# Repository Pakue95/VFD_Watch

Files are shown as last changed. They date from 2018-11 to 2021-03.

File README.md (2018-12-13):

# VFD Watch Project

This project was originally inspired by Johngineer's [ChronodeVFD](https://blog.adafruit.com/2014/10/29/chronodevfd-a-watch-by-johngineer-wearablewednesday/) project. However no concrete design information were available therefore this project was born.

The goal was to create a mobile driver circuit for the common IVL2-5/7 vacuum fluorescent display, that is powered by a single cell battery. The datasheet of the display can be found on the [Loststreak](http://loststeak.com/ivl2-75-vfd-datasheets/) blog.

## Circuit elements

### Microcontroller
An **ESP32 WROOM-32** module is used as a microcontroller for the display and wireless communication. It is interfaced fo r programming via a **FT231XS** USB-Serial converter.

### Battery voltage regulation
The choice for the battery driver IC fell on the **MP3120** single cell 1.2A step up module as it can handle very low battery voltages and still start up. If wireless communication is used during the power up of the display the step-up module won't be able to supply enough power from a normal Alkaline cell to the ESP32 and a brownout reset will occur. Primary lithium cells, 2 Alkaline batteries or LiIon should be sufficient to power all functions at the same time.

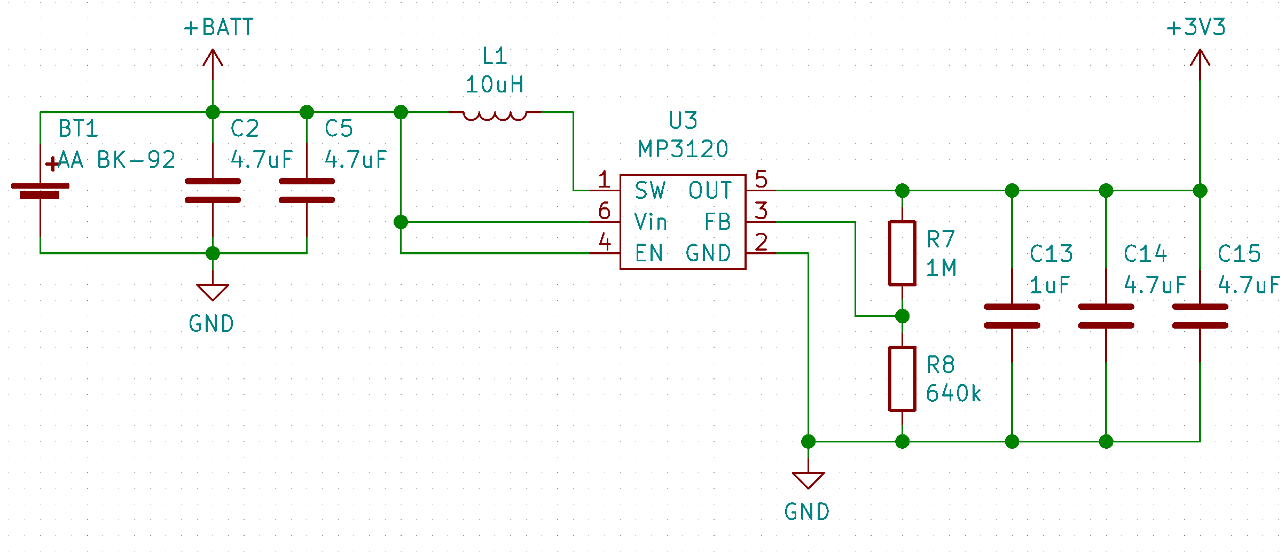
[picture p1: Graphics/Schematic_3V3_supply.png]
Schematic of the 3.3V supply


### VFD driver
The display is driven by a 24V rail from a **MCP1663** step-up converter and high-side switches (**TBD62783A**) to power the segments. The filament is driven from the 3.3V rail and pulse-modulated from a motor H-bridge driver (**DRV8837C**) to achieve an equivalent to the 2.4V @ 60mA power conditions described in the datasheet. The H-bridge design allows an equal brightness of the characters without the use of a complex center-tapped AC circuit.

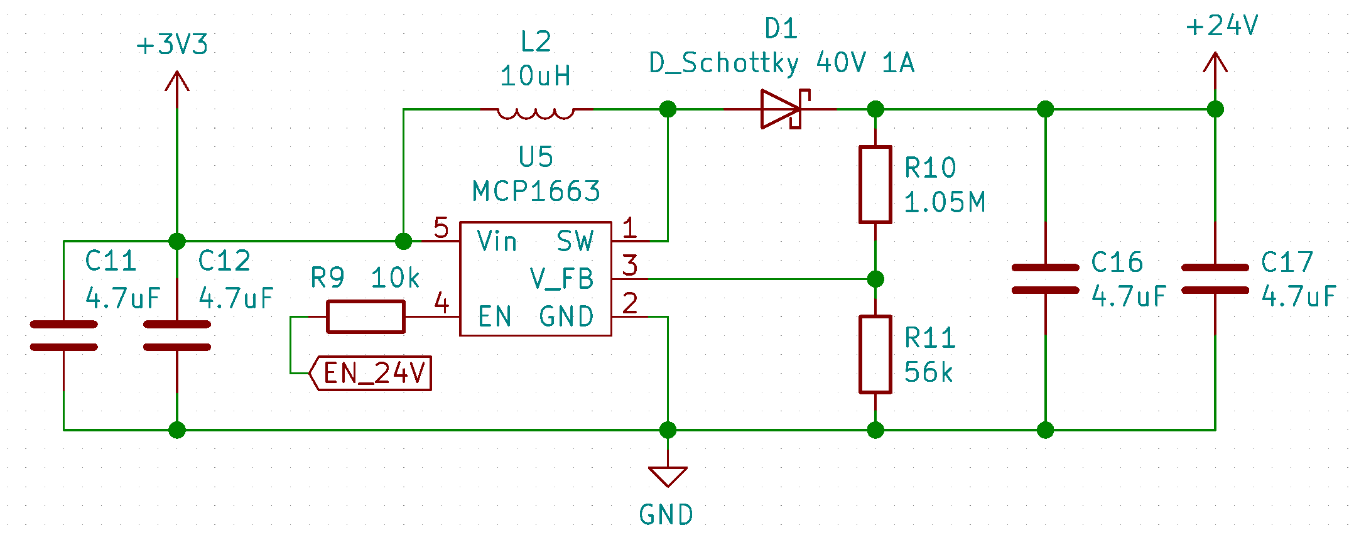
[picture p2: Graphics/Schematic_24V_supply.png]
Schematic of the 24V supply


## Software

### Functions

```cpp
void begin(uint8_t dutyCycle, uint32_t freqMultiplex, uint32_t freqHeat)
```

* ```dutyCycle``` sets the PWM duty cycle of the heating filament. 0-255; typical 120.
* ```freqMultiplex``` sets the rate at which the characters are cycled though (1kHz -> 200Hz total refresh of the display). The timing is controlled in the background by an interrupt function that calls for an update of the currently displayed character. This process runs on core 0 of the ESP32, therefore during WiFi use the display can flicker a bit.
* ```freqHeat``` sets the frequency of the heating filament PWM. The value should be in the kHz range.

```cpp
void deactivate()
```
Turns of the heating filament and the 24V rail to preserve power.

```cpp
void activate()
```
Turns the display back on after a ```deactivate()```.

```cpp
void setHours(uint8_t hours)
```
Sets the first two digits. Range 0-99.

```cpp
void setMinutes(uint8_t minutes)
```
Sets the last two digits. Range 0-99.

```cpp
void setCharacter(char character, int pos)
```
Displays a char (```a-z; 0-9; '-'```) at position ```pos``` (```0-3```)

```cpp
void print(char* text)
```
Similar to ```setCharacter()``` but it displays the first 4 chars of the array.

```cpp
void setSegment(uint8_t segments, uint8_t pos);
```
Sets specific segments of a digit through the use of a byte mask (least to most significant bit). E.g. ```0b00101000``` would set segments ```d``` & ```f```. ```pos``` declares the digit to be changed (```0-3```).

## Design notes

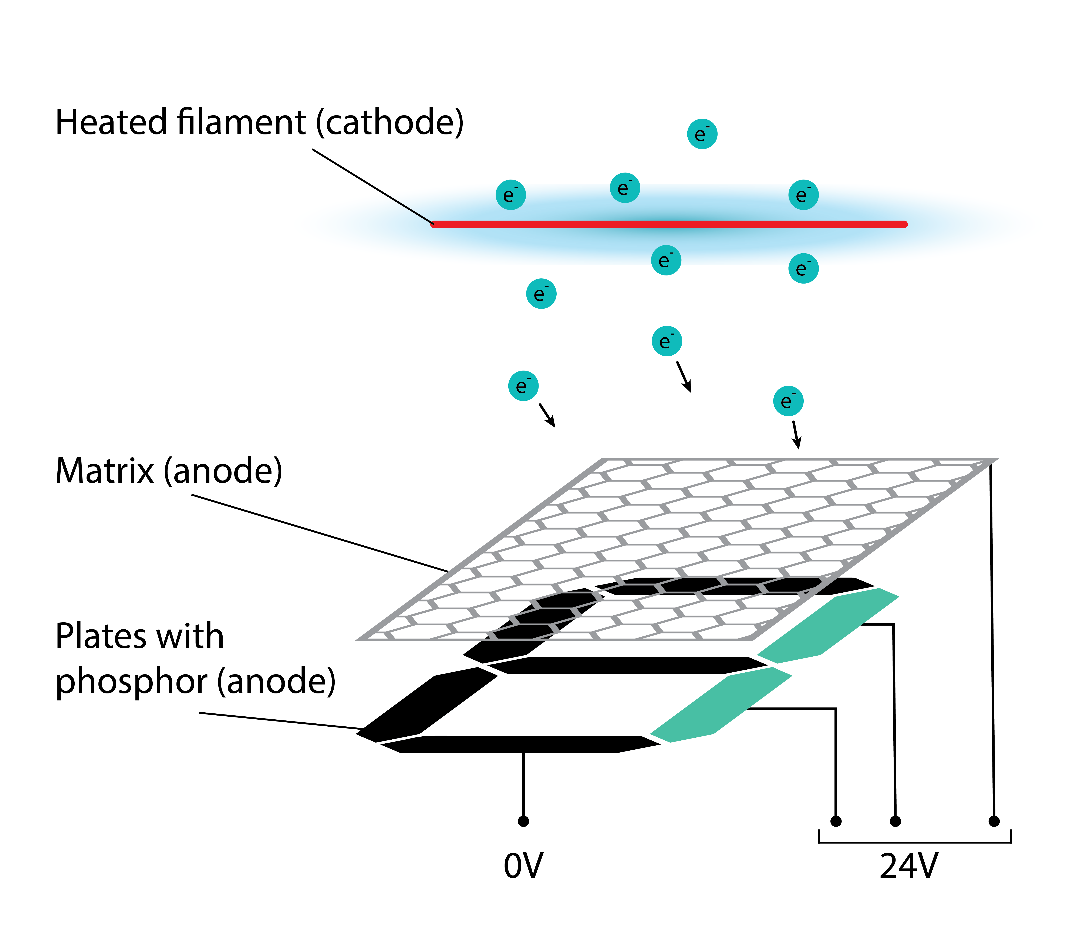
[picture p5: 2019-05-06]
Graphics/VFD_Function/VFD_Function-01.png

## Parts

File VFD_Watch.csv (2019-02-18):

Id | Designator | Package | Quantity | Designation | Supplier and ref
1 | R19,R18,R5,R6,R9,R12,R13,R14,R15,R16,R17 | R_0805_2012Metric | 11 | 10k
2 | C19 | C_1206_3216Metric | 1 | 10uF
3 | U10 | ILV2-5_7 | 1 | IVL2-7_5
4 | REF**,REF**,REF**,REF** | Strap_Holes | 4 | Strap_Holes
5 | U6 | ESP32-WROOM | 1 | ESP32-WROOM
6 | U8,U9 | SOP-18_7.0x12.5mm_P1.27mm | 2 | TBD62783A
7 | U4 | SSOP-20_3.9x8.7mm_P0.635mm | 1 | FT231XS
8 | J2 | PinHeader_1x04_P1.27mm_Vertical | 1 | I2C_Con
9 | U7 | SSOP-28_5.3x10.2mm_P0.65mm | 1 | MCP23017_SS
10 | REF**,REF**,REF**,REF** | Wire_Holes | 4 | Wire_Holes
11 | U1 | SOT-23-5 | 1 | MIC5219-3.3YM5
12 | L2,L1 | L_Taiyo-Yuden_MD-5050 | 2 | 10uH
13 | BT1 | BK-92 | 1 | AA BK-92
14 | C1,C2,C5,C6,C8,C11,C12,C14,C15,C16,C17 | C_0805_2012Metric | 11 | 4.7uF
15 | C3,C4 | C_0805_2012Metric | 2 | 47pF
16 | C9,C10,C18 | C_0805_2012Metric | 3 | 100nF
17 | C13 | C_0805_2012Metric | 1 | 1uF
18 | D1 | D_SOD-323 | 1 | D_Schottky 40V 1A
19 | J1 | USB_Micro-B_Molex_47346-0001 | 1 | USB_B_Micro
20 | Q1 | SOT-363_SC-70-6 | 1 | MBT3904DW1
21 | R1,R2 | R_1206_3216Metric | 2 | 0R
22 | R3,R4 | R_0805_2012Metric | 2 | 27
23 | R7 | R_0805_2012Metric | 1 | 1M
24 | R8 | R_0805_2012Metric | 1 | 640k
25 | R10 | R_0805_2012Metric | 1 | 1.05M
26 | R11 | R_0805_2012Metric | 1 | 56k
27 | SW1 | SW_SPST_EVQP7A | 1 | B1
28 | SW2 | SW_SPST_EVQP7A | 1 | B2
29 | SW3 | SW_SPST_EVQP7A | 1 | B_RES
30 | SW4 | SW_SPST_EVQP7A | 1 | B_0
31 | U2 | WSON-8-1EP_2x2mm_P0.5mm_EP0.9x1.6mm | 1 | DRV8837C
32 | U3 | TSOT-23-6 | 1 | MP3120
33 | U5 | TSOT-23-5 | 1 | MCP1663
34 | C7 | C_0805_2012Metric | 1 | 470pF

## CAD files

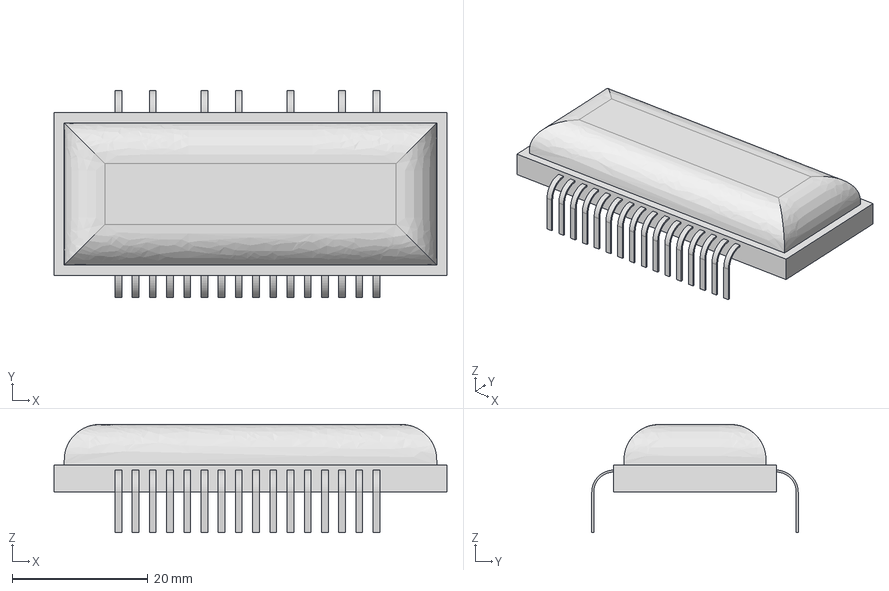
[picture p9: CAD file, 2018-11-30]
3D/VFD_Display v1.step
58.0 x 30.5 x 16.0 mm

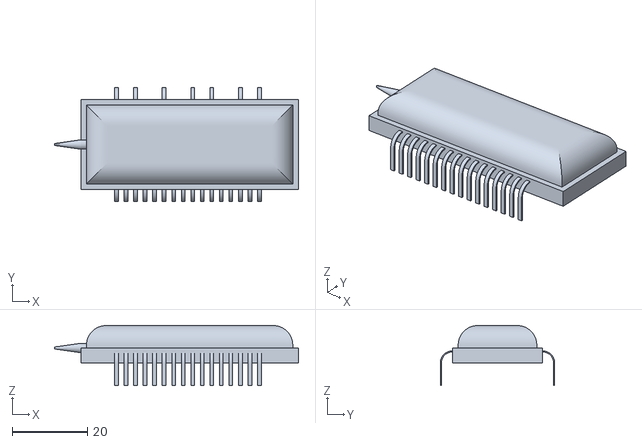
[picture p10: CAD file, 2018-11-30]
3D/VFD_Display v2.stl
65.0 x 30.5 x 16.0

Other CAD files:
3D/VFD_Display v1.iges

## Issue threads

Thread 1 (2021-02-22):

Setting time with buttons

Oliver614, 2021-02-22:
Hi!

I love the project but I'm not very familiar with c++.
Looking through the code there is no obvious way to set the time without WIFI.
Could you please describe a way I could use the buttons to set the time rather than needing to be attached to WIFI?

Regards,
Ollie

Pakue95, 2021-02-26:
Hey Ollie,

Thank!

I use the ESP32 [internal system time](https://docs.espressif.com/projects/esp-idf/en/latest/esp32/api-reference/system/system_time.html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), which is set via NTP, to track the time. You can set is manually if you want with settimeofday() or use a library like this [one](https://www.arduinolibraries.info/libraries/esp32-time).
[Here](https://github.com/Pakue95/VFD_Watch/blob/a7a951d7522ca1ebe2ff7beca40939c133f14d9f/Code/src/main.cpp#L64) is where the time is set and written to the display if you want to have a go at it.

I might be able to implement something over the weekend to set the time with the buttons.

Oliver614, 2021-02-26:
Thankyou that would be interesting to see! i dont know C++ yet so i wouldn't even know to start. but i basically started to write the software again in python as a learning exercise.
I saw there were some python files in the code folder but it was just an empty file. any reason for this? or was it ssomething you were going to work on?

Pakue95, 2021-03-14:
I added a bit of code to set the time with the buttons once the wifi connection fails for a few seconds. Left/Right -> up/down; middle -> set the minutes/finish.

I created the python folder for playing around with [MicroPython](https://micropython.org), but never pushed the code due to some bug with mapping I2C to the pins I had chosen.

Oliver614, 2021-03-14:
Okay nice, I'll have a look. I actually got it working with micropython today but the i2c does seem a little slow to update I'm not sure why but it might be the library I'm using.

Closed 2021-03-14.

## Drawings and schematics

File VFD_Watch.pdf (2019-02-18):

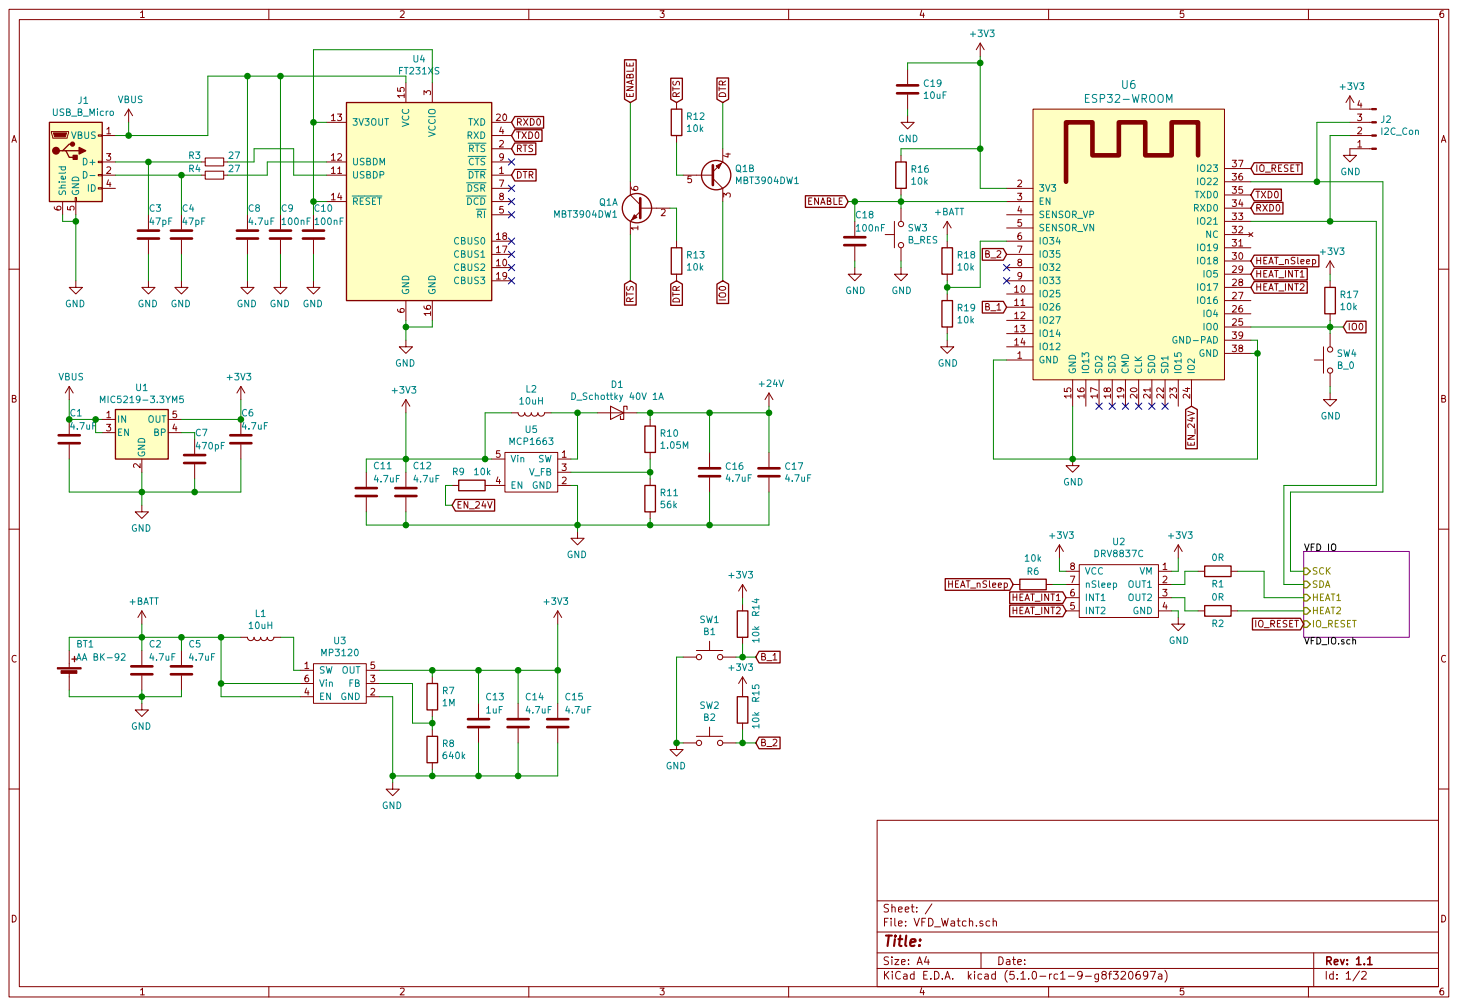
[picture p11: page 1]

2 EN 3 BP 4 OUT 5 U1 MIC5219-3.3YM5 VFD IO

File: VFD_Watch.sch Sheet: / GND

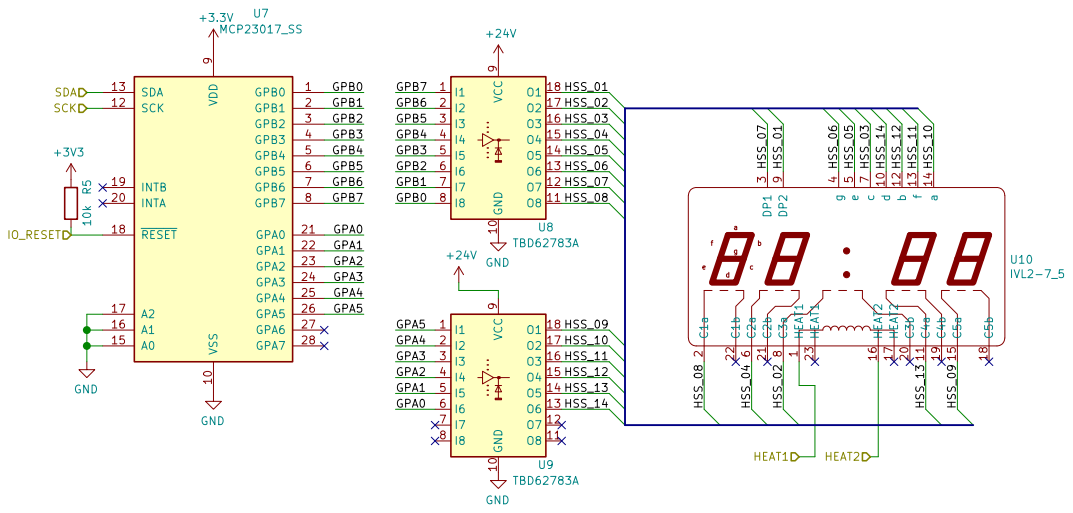
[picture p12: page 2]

File: VFD_IO.sch Sheet: /VFD IO/
Id: 2/2 Title:

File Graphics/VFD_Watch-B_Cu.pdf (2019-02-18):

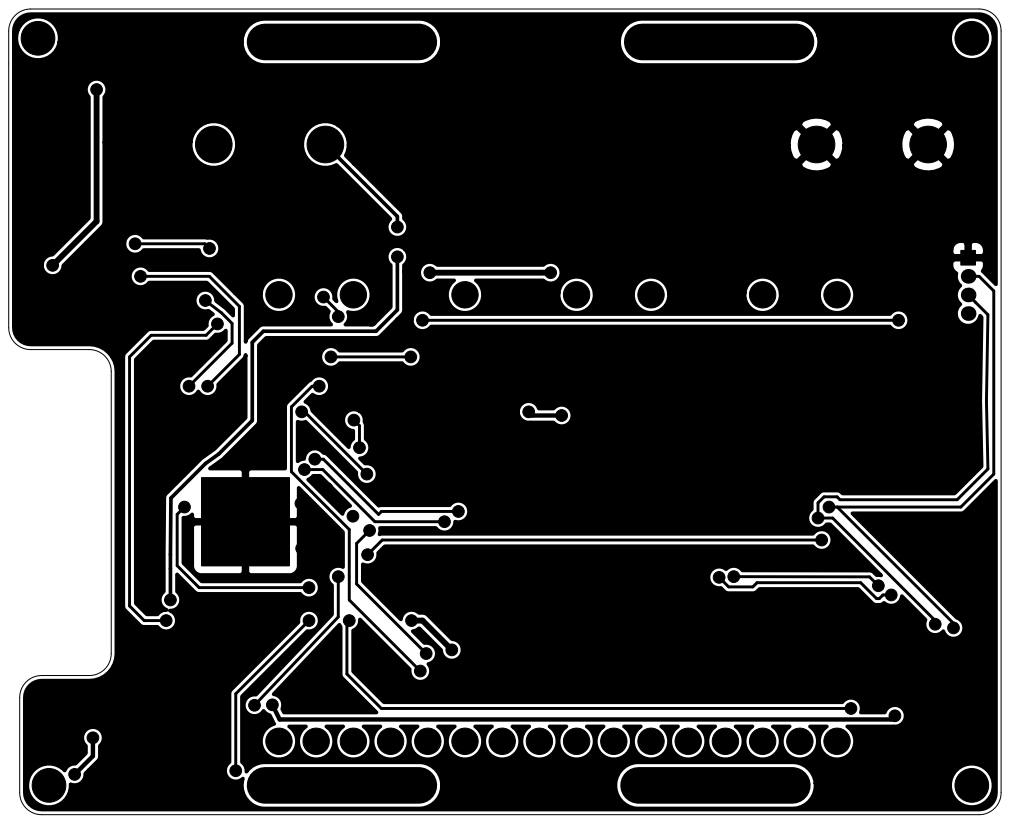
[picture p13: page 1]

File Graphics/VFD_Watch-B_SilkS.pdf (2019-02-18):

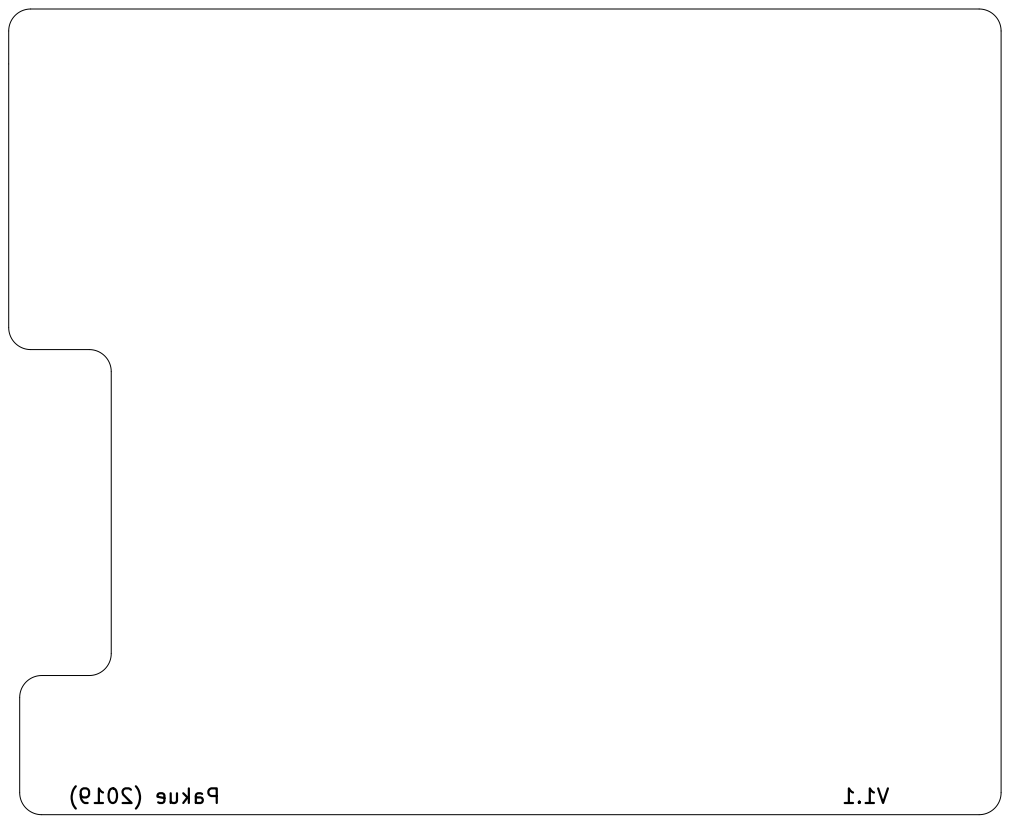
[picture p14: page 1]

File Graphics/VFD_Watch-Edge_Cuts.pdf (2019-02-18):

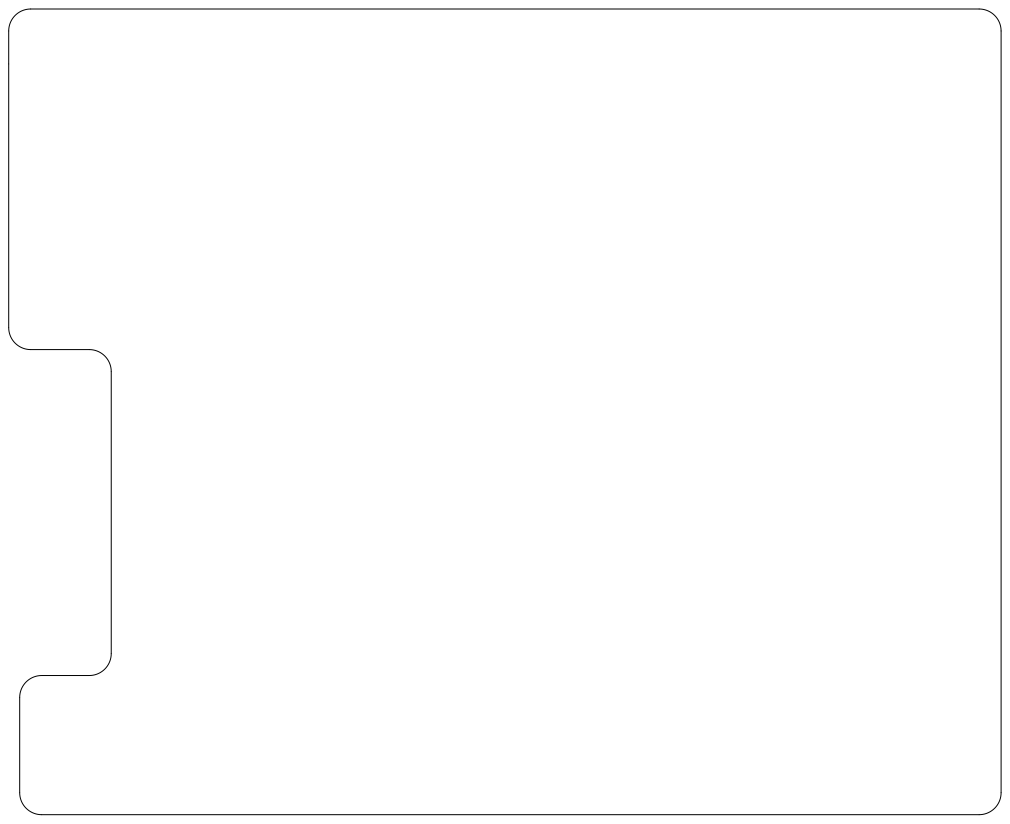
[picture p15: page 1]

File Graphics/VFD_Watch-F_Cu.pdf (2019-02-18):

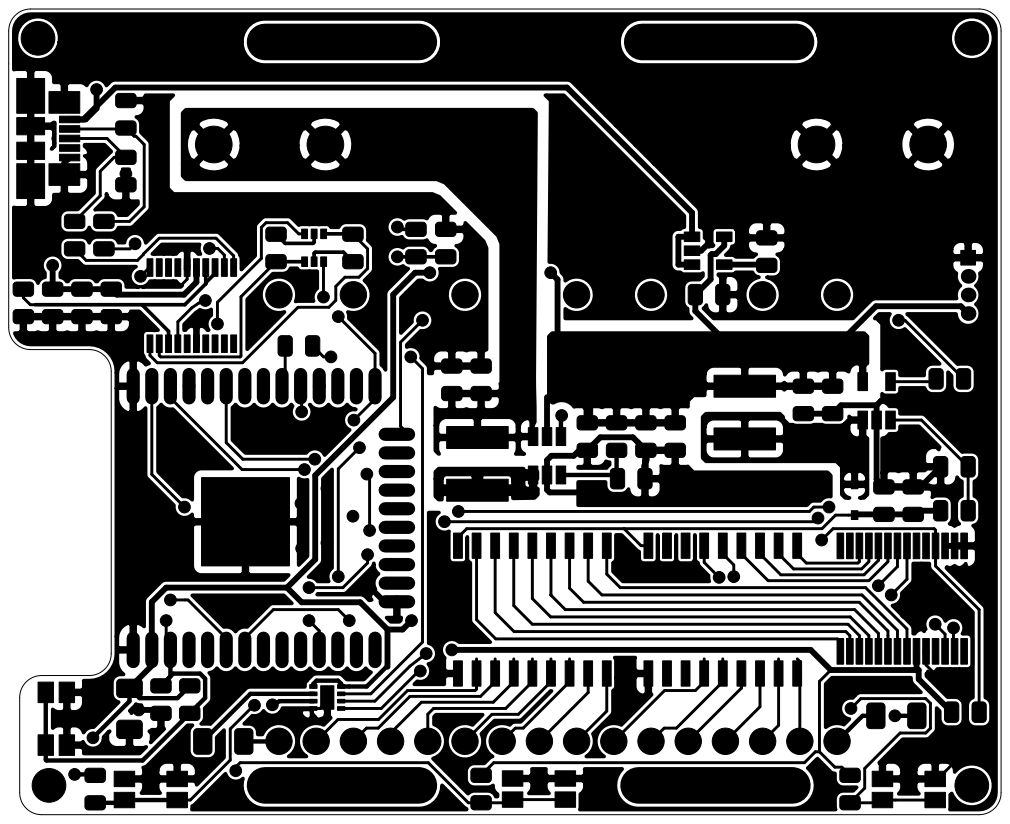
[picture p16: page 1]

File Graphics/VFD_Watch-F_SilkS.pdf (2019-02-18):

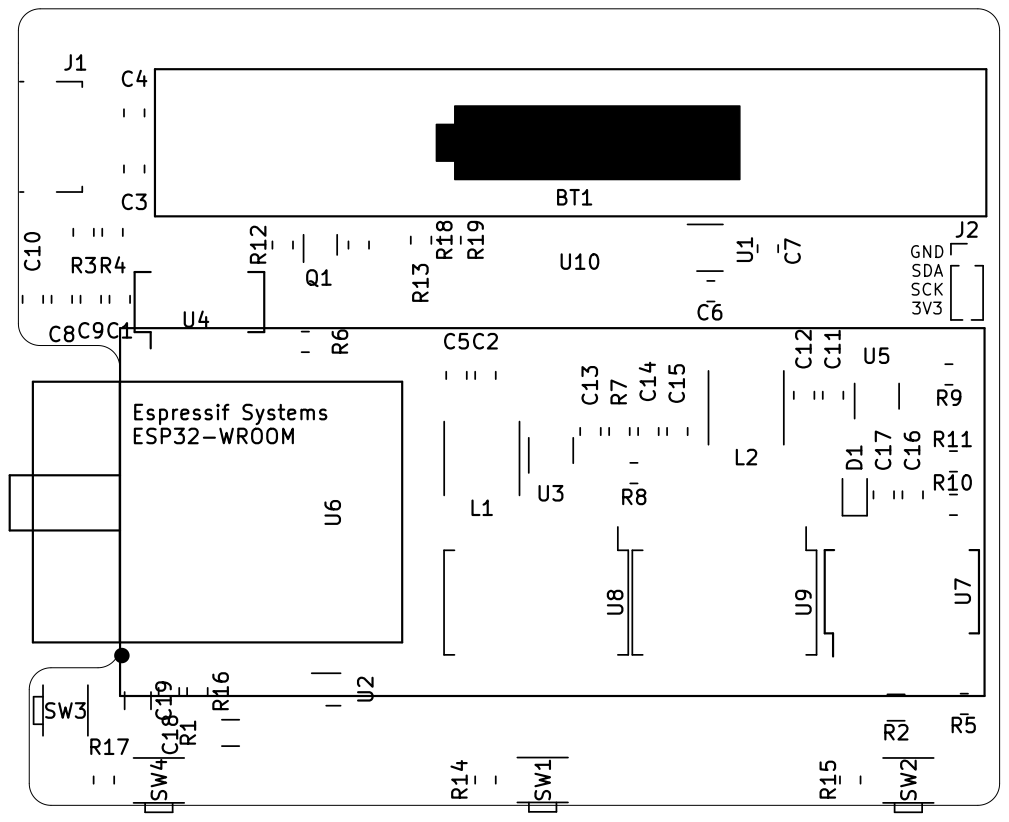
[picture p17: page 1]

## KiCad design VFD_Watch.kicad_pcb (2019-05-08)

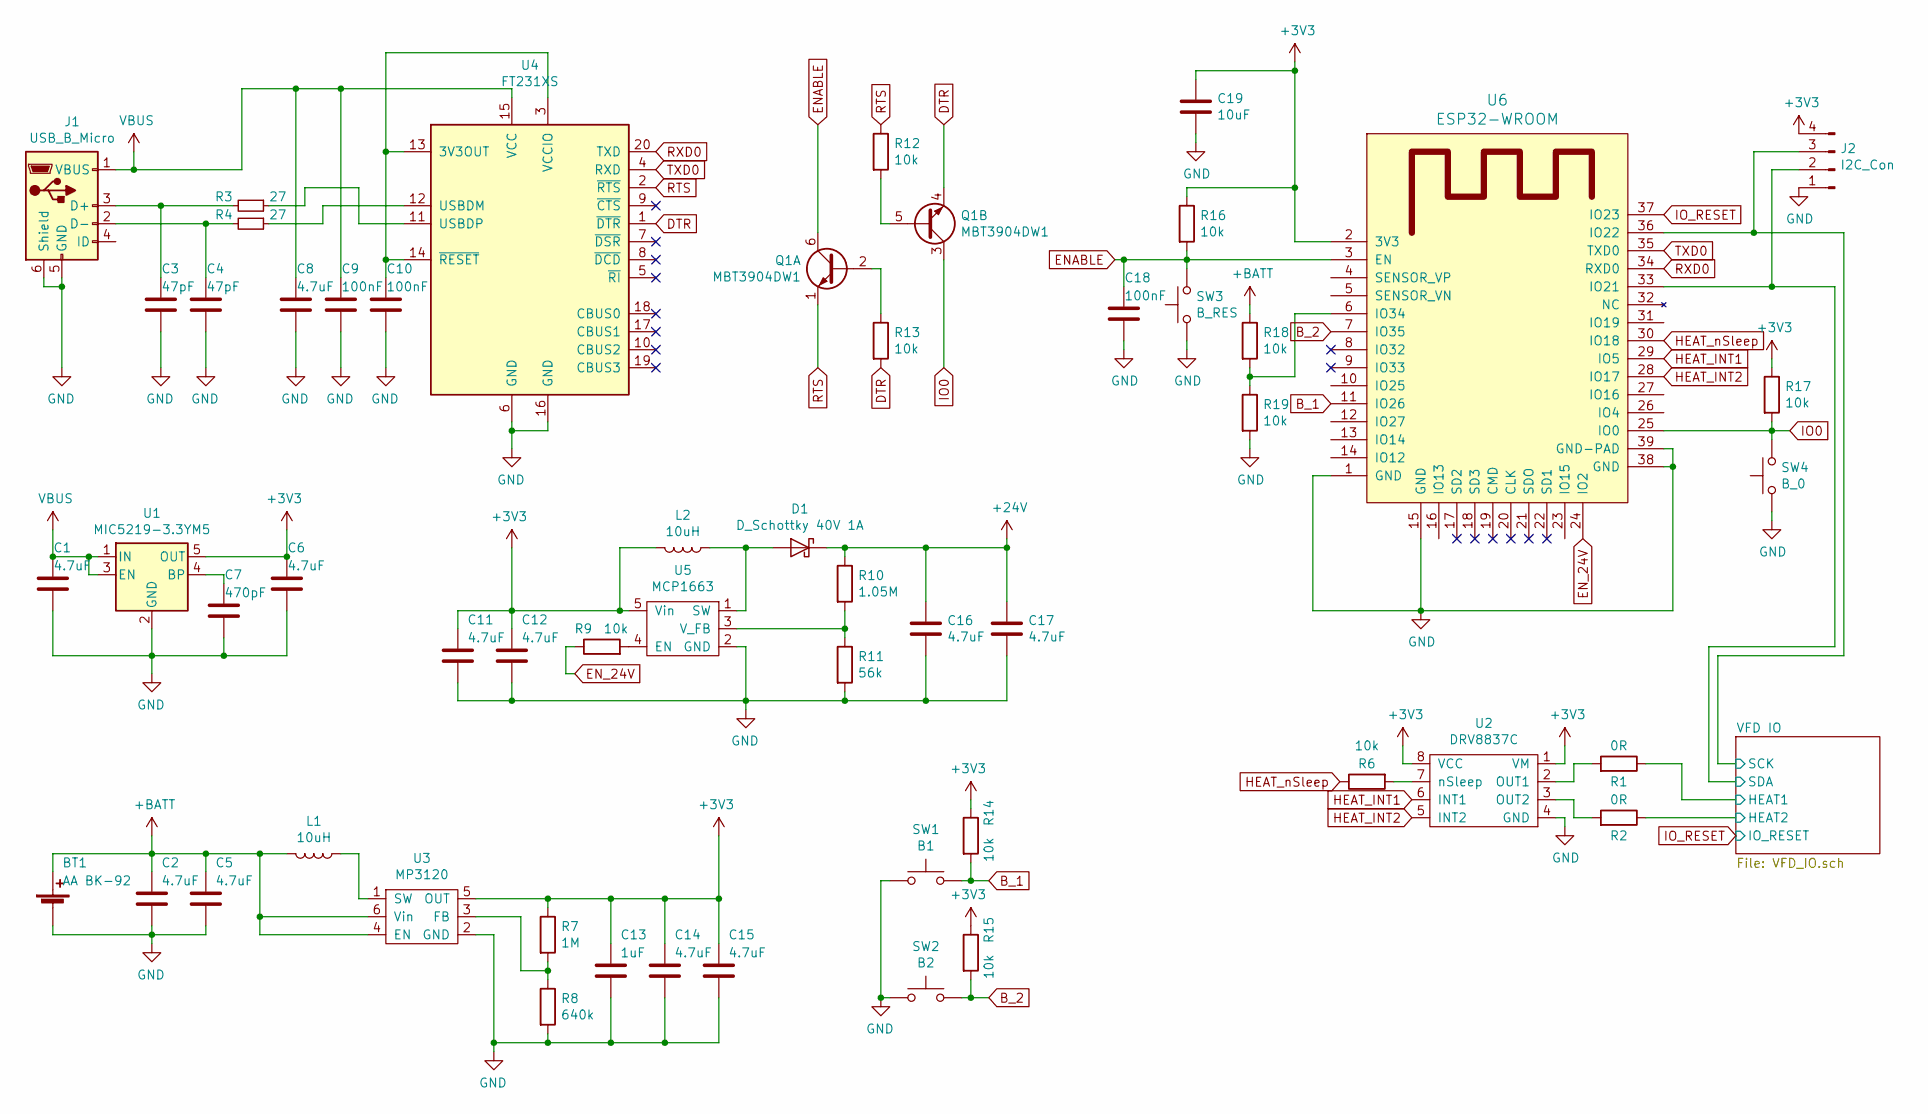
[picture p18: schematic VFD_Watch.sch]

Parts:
BT1: AA BK-92; BK-92
C1, C2, C5, C6, C8, C11, C12, C14, C15, C16, C17: 4.7uF; C_0805_2012Metric
C3, C4: 47pF; C_0805_2012Metric
C7: 470pF; C_0805_2012Metric
C9, C10, C18: 100nF; C_0805_2012Metric
C13: 1uF; C_0805_2012Metric
C19: 10uF; C_1206_3216Metric
D1: D_Schottky 40V 1A; D_SOD-323
J1: USB_B_Micro; USB_Micro-B_Molex_47346-0001
J2: I2C_Con; PinHeader_1x04_P1.27mm_Vertical
L1, L2: 10uH; L_Taiyo-Yuden_MD-5050
Q1: MBT3904DW1; SOT-363_SC-70-6
R1, R2: 0R; R_1206_3216Metric
R3, R4: 27; R_0805_2012Metric
R6, R9, R12, R13, R14, R15, R16, R17, R18, R19: 10k; R_0805_2012Metric
R7: 1M; R_0805_2012Metric
R8: 640k; R_0805_2012Metric
R10: 1.05M; R_0805_2012Metric
R11: 56k; R_0805_2012Metric
SW1: B1; SW_SPST_EVQP7A
SW2: B2; SW_SPST_EVQP7A
SW3: B_RES; SW_SPST_EVQP7A
SW4: B_0; SW_SPST_EVQP7A
U1: MIC5219-3.3YM5; SOT-23-5
U2: DRV8837C; WSON-8-1EP_2x2mm_P0.5mm_EP0.9x1.6mm
U3: MP3120; TSOT-23-6
U4: FT231XS; SSOP-20_3.9x8.7mm_P0.635mm
U5: MCP1663; TSOT-23-5
U6: ESP32-WROOM

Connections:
+24V: C16.1, C17.1, D1.1 (K), R10.1; also elsewhere on the board
+BATT: BT1.1 (+), C2.1, C5.1, L1.2, R18.1, U3.4 (EN), U3.6 (Vin)
/VFD IO/HEAT1: R1.1; also elsewhere on the board
/VFD IO/HEAT2: R2.1; also elsewhere on the board
/VFD IO/SCK: J2.3, U6.36 (IO22); also elsewhere on the board
/VFD IO/SDA: J2.2, U6.33 (IO21); also elsewhere on the board
B_1: R14.2, SW1.2, U6.11 (IO26)
B_2: R15.2, SW2.2, U6.7 (IO35)
DTR: Q1.4 (E2), R13.2, U4.1 (~DTR)
ENABLE: C18.1, Q1.6 (C1), R16.2, SW3.2, U6.3 (EN)
EN_24V: R9.1, U6.24 (IO2)
GND: BT1.2 (-), C1.2, C2.2, C3.2, C4.2, C5.2, C6.2, C7.2, C8.2, C9.2, C10.2, C11.2, C12.2, C13.2, C14.2, C15.2, C16.2, C17.2, C18.2, C19.2, J1.5 (GND), J1.6 (Shield), J2.1, R8.2, R11.2, R19.2, SW1.1, SW2.1, SW3.1, SW4.1, U1.2 (GND), U2.4 (GND), U2.9 (GND), U3.2 (GND), U4.6 (GND), U4.16 (GND), U5.2 (GND), U6.1 (GND), U6.15 (GND), U6.38 (GND), U6.39 (GND-PAD); also elsewhere on the board
HEAT_INT1: U2.6 (INT1), U6.29 (IO5)
HEAT_INT2: U2.5 (INT2), U6.28 (IO17)
HEAT_nSleep: R6.1, U6.30 (IO18)
IO0: Q1.3 (C2), R17.2, SW4.2, U6.25 (IO0)
IO_RESET: U6.37 (IO23); also elsewhere on the board
unnamed: C3.1, J1.3 (D+), R3.2
unnamed: C4.1, J1.2 (D-), R4.2
unnamed: C7.1, U1.4 (BP)
unnamed: C10.1, U4.3 (VCCIO), U4.13 (3V3OUT), U4.14 (~RESET)
unnamed: D1.2 (A), L2.1, U5.1 (SW)
unnamed: L1.1, U3.1 (SW)
unnamed: Q1.2 (B1), R13.1
unnamed: Q1.5 (B2), R12.2
unnamed: R1.2, U2.2 (OUT1)
unnamed: R2.2, U2.3 (OUT2)
unnamed: R3.1, U4.11 (USBDP)
unnamed: R4.1, U4.12 (USBDM)
unnamed: R6.2, U2.7 (nSleep)
unnamed: R7.2, R8.1, U3.3 (FB)
unnamed: R9.2, U5.4 (EN)
unnamed: R10.2, R11.1, U5.3 (V_FB)
unnamed: R18.2, R19.1, U6.6 (IO34)
RTS: Q1.1 (E1), R12.1, U4.2 (~RTS)
RXD0: U4.20 (TXD), U6.34 (RXD0)
TXD0: U4.4 (RXD), U6.35 (TXD0)
VBUS: C1.1, C8.1, C9.1, J1.1 (VBUS), U1.1 (IN), U1.3 (EN), U4.15 (VCC)

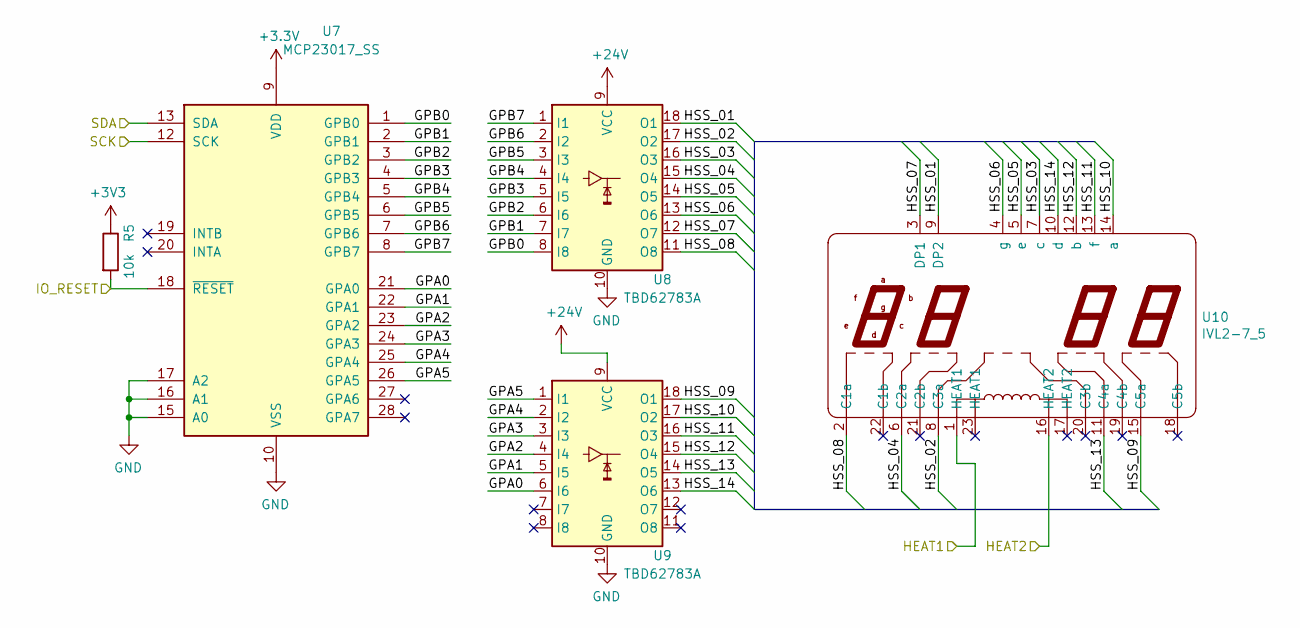
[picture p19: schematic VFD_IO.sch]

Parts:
R5: 10k; R_0805_2012Metric
U7: MCP23017_SS; SSOP-28_5.3x10.2mm_P0.65mm
U8, U9: TBD62783A; SOP-18_7.0x12.5mm_P1.27mm
U10: IVL2-7_5; ILV2-5_7

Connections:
+24V: U8.9 (VCC), U9.9 (VCC); also elsewhere on the board
/VFD IO/GPA0: U7.21 (GPA0), U9.6 (I6)
/VFD IO/GPA1: U7.22 (GPA1), U9.5 (I5)
/VFD IO/GPA2: U7.23 (GPA2), U9.4 (I4)
/VFD IO/GPA3: U7.24 (GPA3), U9.3 (I3)
/VFD IO/GPA4: U7.25 (GPA4), U9.2 (I2)
/VFD IO/GPA5: U7.26 (GPA5), U9.1 (I1)
/VFD IO/GPB0: U7.1 (GPB0), U8.8 (I8)
/VFD IO/GPB1: U7.2 (GPB1), U8.7 (I7)
/VFD IO/GPB2: U7.3 (GPB2), U8.6 (I6)
/VFD IO/GPB3: U7.4 (GPB3), U8.5 (I5)
/VFD IO/GPB4: U7.5 (GPB4), U8.4 (I4)
/VFD IO/GPB5: U7.6 (GPB5), U8.3 (I3)
/VFD IO/GPB6: U7.7 (GPB6), U8.2 (I2)
/VFD IO/GPB7: U7.8 (GPB7), U8.1 (I1)
/VFD IO/HEAT1: U10.1 (HEAT1); also elsewhere on the board
/VFD IO/HEAT2: U10.16 (HEAT2); also elsewhere on the board
/VFD IO/HSS_01: U8.18 (O1), U10.9 (DP2)
/VFD IO/HSS_02: U8.17 (O2), U10.8 (C3a)
/VFD IO/HSS_03: U8.16 (O3), U10.7 (c)
/VFD IO/HSS_04: U8.15 (O4), U10.6 (C2a)
/VFD IO/HSS_05: U8.14 (O5), U10.5 (e)
/VFD IO/HSS_06: U8.13 (O6), U10.4 (g)
/VFD IO/HSS_07: U8.12 (O7), U10.3 (DP1)
/VFD IO/HSS_08: U8.11 (O8), U10.2 (C1a)
/VFD IO/HSS_09: U9.18 (O1), U10.15 (C5a)
/VFD IO/HSS_10: U9.17 (O2), U10.14 (a)
/VFD IO/HSS_11: U9.16 (O3), U10.13 (f)
/VFD IO/HSS_12: U9.15 (O4), U10.12 (b)
/VFD IO/HSS_13: U9.14 (O5), U10.11 (C4a)
/VFD IO/HSS_14: U9.13 (O6), U10.10 (d)
/VFD IO/SCK: U7.12 (SCK); also elsewhere on the board
/VFD IO/SDA: U7.13 (SDA); also elsewhere on the board
GND: U7.10 (VSS), U7.15 (A0), U7.16 (A1), U7.17 (A2), U8.10 (GND), U9.10 (GND); also elsewhere on the board
IO_RESET: R5.2, U7.18 (~RESET~); also elsewhere on the board

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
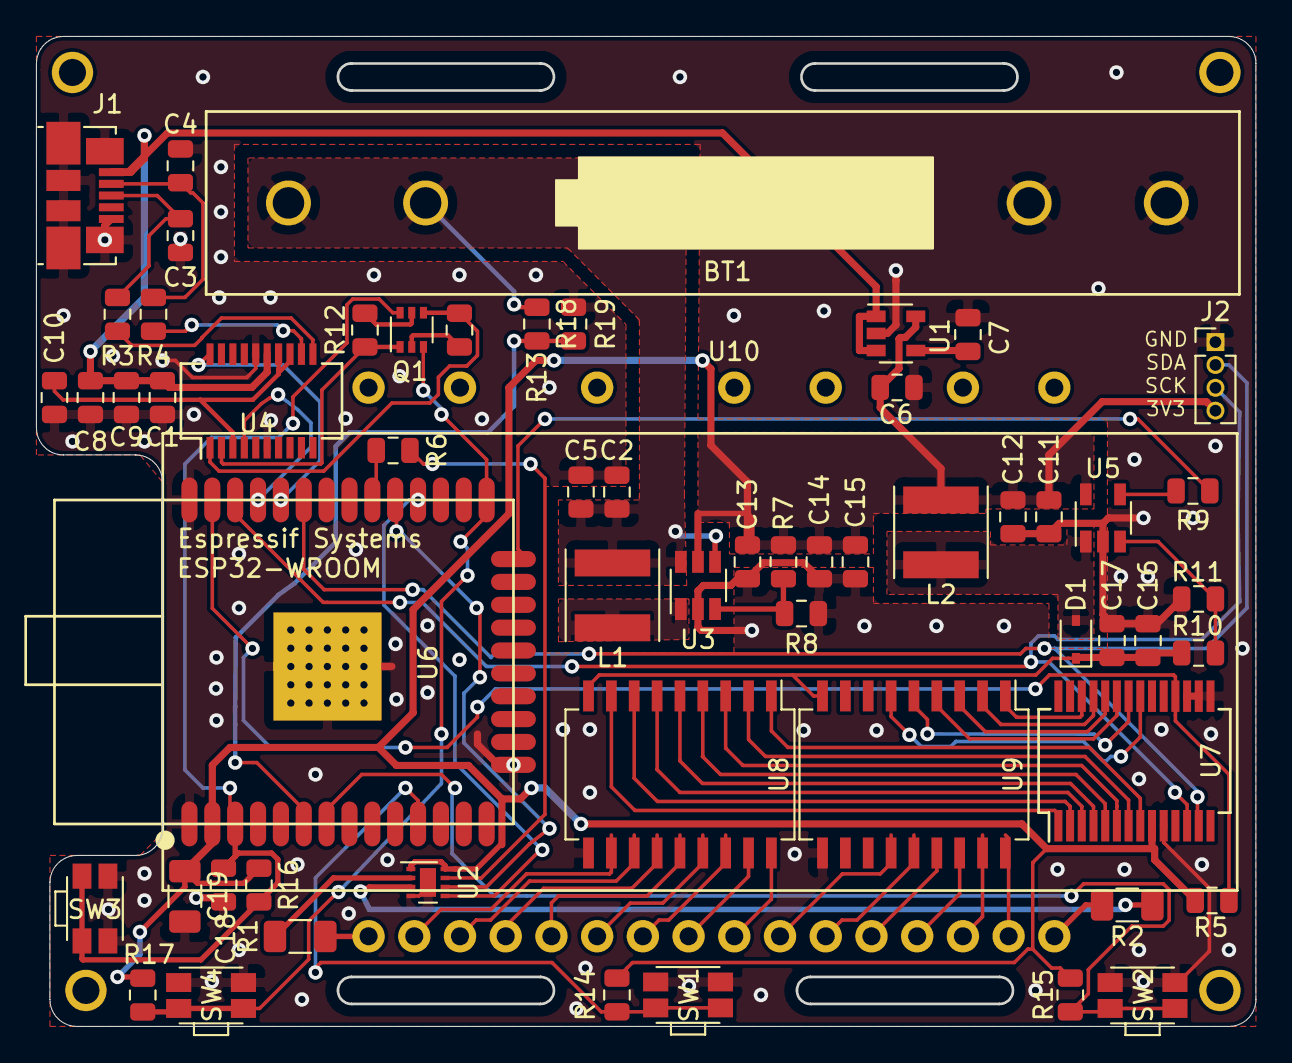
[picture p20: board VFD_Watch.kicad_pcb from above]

Board: 2 copper layers, 67.8 x 55.0 mm, 59 parts (0 on the bottom side), 67 nets.

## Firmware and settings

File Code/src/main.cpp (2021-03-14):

#include <Arduino.h>
#include <Vfd_Display.h>
#include <WiFi.h>
#include <esp_wifi.h>
#include <WiFiUdp.h>
#include "Password.h"
#include "ManualTimeSet.h"

#define NTP_SERVER "de.pool.ntp.org"
#define TZ_INFO "WEST-1DWEST-2,M3.5.0/02:00:00,M10.5.0/03:00:00" // Western European Time

WiFiUDP udp;


TaskHandle_t vfdTask;
vfdDisplay vfd;
#include "Animations.h"



int seconds = 0;
int minutes = 0;
struct tm local;

Ticker updateTime;


void initialBoot(){
  Serial.begin(115200);

  WiFi.begin(ssid, password);
  for(int i = 0, time = 0; WiFi.status() != WL_CONNECTED; ++i, ++time) {
    i = i % 4;
    wifiAnimation(i);
    Serial.print(".");
    if(time > 10){
      startManualTimeSet(vfd); //
      WiFi.mode( WIFI_OFF );
      return;
    }
  }

  configTzTime(TZ_INFO, NTP_SERVER); // config system time via NTP server
  getLocalTime(&local, 10000);       // get time for 10s
  setenv("TZ", TZ_INFO, 1); // reset timezone
  tzset();

  WiFi.mode( WIFI_OFF );
}


void setup() {
  Serial.begin(115200);
  vfd.begin(80, 1000, 10000);
  esp_sleep_wakeup_cause_t wakeup_cause = esp_sleep_get_wakeup_cause(); // check wakeup reason
  Serial.println(wakeup_cause);
  if (wakeup_cause != ESP_SLEEP_WAKEUP_EXT0) initialBoot();  // external reset -> initialize



  updateTime.attach(2, [](){
    // setup time
    vfd.setDP(1,1);
    time_t now;
    time(&now);
    tm *time = localtime(&now);
    
    // Serial.println(&local, "Date: %d.%m.%y  Time: %H:%M:%S"); // print formated time
    vfd.setMinutes(time->tm_min);
    vfd.setHours(time->tm_hour);
  });

}

void loop() {


}

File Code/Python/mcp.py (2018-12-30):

# Copyright (c) 2014 Adafruit Industries
# Author: Tony DiCola, ported for Micropython ESP8266 by Cefn Hoile
#
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
OUT     = 0
IN      = 1
HIGH    = True
LOW     = False

RISING  = 1
FALLING = 2
BOTH    = 3

PUD_OFF = 0
PUD_DOWN= 1
PUD_UP  = 2

class MCP():
    """Base class to represent an MCP230xx series GPIO extender.  Is compatible
    with the Adafruit_GPIO BaseGPIO class so it can be used as a custom GPIO
    class for interacting with device.
    """

    def __init__(self, address=0x20, gpioScl=5, gpioSda=4):
        """Initialize MCP230xx at specified I2C address and bus number.  If bus
        is not specified it will default to the appropriate platform detected bus.
        """
        self.address = address
        self.i2c = I2C(scl=Pin(gpioScl),sda=Pin(gpioSda))
        # Assume starting in ICON.BANK = 0 mode (sequential access).
        # Compute how many bytes are needed to store count of GPIO.
        self.gpio_bytes = self.NUM_GPIO//8
        # Buffer register values so they can be changed without reading.
        self.iodir = bytearray(self.gpio_bytes)  # Default direction to all inputs.
        self.gppu = bytearray(self.gpio_bytes)  # Default to pullups disabled.
        self.gpio = bytearray(self.gpio_bytes)
        # Write current direction and pullup buffer state.
        self.write_iodir()
        self.write_gppu()

    def _validate_pin(self, pin):
        """Promoted to mcp implementation from prior Adafruit GPIO superclass"""
        # Raise an exception if pin is outside the range of allowed values.
        if pin < 0 or pin >= self.NUM_GPIO:
            raise ValueError('Invalid GPIO value, must be between 0 and {0}.'.format(self.NUM_GPIO))

    def writeList(self, register, data):
        """Introduced to match the writeList implementation of the Adafruit I2C _device member"""
        return self.i2c.writeto_mem(self.address, register, data)

    def readList(self, register, length):
        """Introduced to match the readList implementation of the Adafruit I2C _device member"""
        return self.i2c.readfrom_mem(self.address, register, length)

    def setup(self, pin, value):
        """Set the input or output mode for a specified pin.  Mode should be
        either OUT or IN.
        """
        self._validate_pin(pin)
        # Set bit to 1 for input or 0 for output.
        if value == IN:
            self.iodir[int(pin/8)] |= 1 << (int(pin%8))
        elif value == OUT:
            self.iodir[int(pin/8)] &= ~(1 << (int(pin%8)))
        else:
            raise ValueError('Unexpected value.  Must be IN or OUT.')
        self.write_iodir()


    def output(self, pin, value):
        """Set the specified pin the provided high/low value.  Value should be
        either HIGH/LOW or a boolean (True = HIGH).
        """
        self.output_pins({pin: value})

    def output_pins(self, pins):
        """Set multiple pins high or low at once.  Pins should be a dict of pin
        name to pin value (HIGH/True for 1, LOW/False for 0).  All provided pins
        will be set to the given values.
        """
        [self._validate_pin(pin) for pin in pins.keys()]
        # Set each changed pin's bit.
        for pin, value in iter(pins.items()):
            if value:
                self.gpio[int(pin/8)] |= 1 << (int(pin%8))
            else:
                self.gpio[int(pin/8)] &= ~(1 << (int(pin%8)))
        # Write GPIO state.
        self.write_gpio()


    def input(self, pin, read=True):
        """Read the specified pin and return HIGH/True if the pin is pulled
        high, or LOW/False if pulled low.
        """
        return self.input_pins([pin], read)[0]

    def input_pins(self, pins, read=True):
        """Read multiple pins specified in the given list and return list of pin values
        HIGH/True if the pin is pulled high, or LOW/False if pulled low.
        """
        [self._validate_pin(pin) for pin in pins]
        if read:
            # Get GPIO state.
            self.read_gpio()
        # Return True if pin's bit is set.
        return [(self.gpio[int(pin/8)] & 1 << (int(pin%8))) > 0 for pin in pins]


    def pullup(self, pin, enabled):
        """Turn on the pull-up resistor for the specified pin if enabled is True,
        otherwise turn off the pull-up resistor.
        """
        self._validate_pin(pin)
        if enabled:
            self.gppu[int(pin/8)] |= 1 << (int(pin%8))
        else:
            self.gppu[int(pin/8)] &= ~(1 << (int(pin%8)))
        self.write_gppu()

    def read_gpio(self):
        self.gpio = self.readList(self.GPIO, self.gpio_bytes)

    def write_gpio(self, gpio=None):
        """Write the specified byte value to the GPIO registor.  If no value
        specified the current buffered value will be written.
        """
        if gpio is not None:
            self.gpio = gpio
        self.writeList(self.GPIO, self.gpio)

    def write_iodir(self, iodir=None):
        """Write the specified byte value to the IODIR registor.  If no value
        specified the current buffered value will be written.
        """
        if iodir is not None:
            self.iodir = iodir
        self.writeList(self.IODIR, self.iodir)

    def write_gppu(self, gppu=None):
        """Write the specified byte value to the GPPU registor.  If no value
        specified the current buffered value will be written.
        """
        if gppu is not None:
            self.gppu = gppu
        self.writeList(self.GPPU, self.gppu)


class MCP23017(MCP):
    """MCP23017-based GPIO class with 16 GPIO pins."""
    # Define number of pins and registor addresses.
    NUM_GPIO = 16
    IODIR    = 0x00
    GPIO     = 0x12
    GPPU     = 0x0C


class MCP23008(MCP):
    """MCP23008-based GPIO class with 8 GPIO pins."""
    # Define number of pins and registor addresses.
    NUM_GPIO = 8
    IODIR    = 0x00
    GPIO     = 0x09
    GPPU     = 0x06

if __name__=="__main__":
    io = MCP23017()
    io.setup(3,IN)
    io.setup(0,OUT)
    io.output(0,HIGH)
    print(io.input(3))

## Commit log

2018-11-30 inital commit
    [ESP32-Footprints.kicad_pcb, ESP32-Footprints.sch, IO_Switches.sch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]
2018-12-05 added PDF schematic
2018-12-07 fixed csv
    [VFD_Watch.csv]
2018-12-07 fixed csv again
    [VFD_Watch.csv]
2018-12-29 fixed numbers as characters display
    [Vfd_Display.cpp, main.cpp]
2018-12-30 fixed the compiler warnings and removes unused functions
    [Vfd_Display.cpp, main.cpp]
2019-02-18 fixed BAT INPUT to allow for LiPo voltages without damaging the ESP32, cleaned up silkscreen, updated graphics
    [VFD_IO.sch, VFD_Watch.csv, VFD_Watch.kicad_pcb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]
2019-05-06 updated Gerbers
    [VFD_Watch-B.Cu.gbr, VFD_Watch-B.Mask.gbr, VFD_Watch-B.Paste.gbr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]
2019-05-06 exported RS-274x gerber format
2019-05-08 added edge cuts lines to the strap slots
    [VFD_Watch-B_Cu.gbr, VFD_Watch-B_Mask.gbr, VFD_Watch-B_SilkS.gbr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]
2019-05-08 last save
    [VFD_Watch.kicad_pcb]
2021-03-14 added a way to set the time with the buttons, once wifi fails
    [main.cpp]
